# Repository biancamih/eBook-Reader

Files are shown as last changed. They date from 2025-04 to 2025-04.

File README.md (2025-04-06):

# OpenBook 
**Autor: Mihai Bianca-Ioana**

## Diagrama Bloc
```
                            +------------------------+
                            | USB-C Connector & ESD  |
                            +------------------------+
                                      |
                                      v
                             +------------------+
                             |   LDO Regulator   |
                             +------------------+
                                      |
                                      v
 +-------------------+       +------------------+       +---------------------+
 | Li-Po Charging IC | ----> | ESP32-C6 WROOM-1 | <-->  |    SD Card          |
 +-------------------+       +------------------+       +---------------------+
                                      |  ^   ^  ^
                                      |  |   |  |
         +------------------+         |  |   |  +---------------------+
         | Environmental     | -------+  |   +----------------+       |
         | Sensor (BME688)   |            |                    |       |
         +------------------+            |  +--------------+  |       |
                                         +->| NOR Flash     |<-+       |
                                         |  +--------------+          |
                                         |                             |
             +---------------+           +->| Battery Gauge |          |
             |   E-Paper     |<--------------+ (MAX17048)   |          |
             |   Driver      |           |  +---------------+          |
             +---------------+           |                             |
                                         +->| RTC (DS3231)  |<---------+
                                         |
                                         +->| Buttons       |
                                            +---------------+
```

## Bill Of  Materials (BOM)
| Component Name | Link | Datasheet Link |
|---|---|---|
| 112ATAARR03ATTEND | [Link](https://store.comet.srl.ro/Catalogue/Product/43497/) | [Link](https://www.attend.com.tw/data/download/file/112A-TAAR-R03.rar) |
| ADAFRUIT_CHIP-LED0603 | [Link](https://www.snapeda.com/parts/KP-1608SURCK/Kingbright/view-part/?ref=search&t=LED%200603) | [Link](https://www.snapeda.com/parts/KP-1608SURCK/Kingbright/datasheet/) |
| CAPCP3225X100N | [Link](https://www.snapeda.com/parts/CPH3225A/Seiko+Instruments/view-part/?ref=eda) | [Link](https://www.snapeda.com/parts/CPH3225A/Seiko%20Instruments/datasheet/) |
| DIOC1608X36N | [Link](https://www.snapeda.com/parts/PGB1010603MR/Littelfuse/view-part/?ref=eda) | [Link](https://www.snapeda.com/parts/PGB1010603MR/Littelfuse%20Inc./datasheet/) |
| EAGLE-LTSPICE_C0402 | [Link](https://componentsearchengine.com/part-view/CC0402MRX5R5BB106/YAGEO) | [Link](https://componentsearchengine.com/Datasheets/2/CC0402MRX5R5BB106.pdf) |
| ESP32_WROVER_AVX---SD0805S020S1R0_AVX_0  | [Link](https://ro.mouser.com/ProductDetail/KYOCERA-AVX/SD0805S020S1R0?qs=jCA%252BPfw4LHbpkAoSnwrdjw%3D%3D) | [Link](https://ro.mouser.com/datasheet/2/40/schottky-3165252.pdf) |
| ESP32_WROVER_BME680_PSON80P300X300X100-8N| [Link](https://www.snapeda.com/parts/BME680/Bosch/view-part/?welcome=home) | [Link](https://www.snapeda.com/parts/BME680/Bosch%20Sensortec/datasheet/) |
| ESP32_WROVER_EAGLE-LTSPICE_C0402 | [Link](https://componentsearchengine.com/part-view/CC0402MRX5R5BB106/YAGEO) | [Link](https://componentsearchengine.com/Datasheets/2/CC0402MRX5R5BB106.pdf) |
| ESP32_WROVER_EAGLE-LTSPICE_R0402 | [Link](https://componentsearchengine.com/part-view/R0402%201%25%20100%20K%20(RC0402FR-07100KL)/YAGEO) | [Link](https://www.yageo.com/upload/media/product/products/datasheet/rchip/PYu-RC_Group_51_RoHS_L_12.pdf)|
| ESP32_WROVER_SPARKFUN-DISCRETESEMI_SOT23-3| [Link](https://componentsearchengine.com/part-view/DMG2305UX-7/Diodes%20Incorporated) | [Link](https://www.diodes.com//assets/Datasheets/DMG2305UX.pdf) |
| ESP32_WROVER_SPARKFUN-IC-POWER_SOT23-5 | [Link](https://ro.mouser.com/ProductDetail/Microchip-Technology/MCP73831T-5ACI-OT?qs=hH%252BOa0VZEiAcgAcEkuamXg%3D%3D) | [Link](https://ro.mouser.com/datasheet/2/268/MCP73831_Family_Data_Sheet_DS20001984H-3441711.pdf) |
| ESP32C6_VARISTOR_CT/CN1812 | [Link](https://ro.mouser.com/ProductDetail/EPCOS-TDK/B72520T0350K062?qs=dEfas%2FXlABIszF52uu7vrg%3D%3D) | [Link](https://www.tdk-electronics.tdk.com/inf/75/db/CTVS_14/Surge_protection_series.pdf) |
| FH34SRJ24S05SH99 | [Link](https://ro.mouser.com/ProductDetail/Hirose-Connector/FH34SRJ-24S-0.5SH99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) | [Link](https://ro.mouser.com/datasheet/2/185/FH34SRJ_24S_0_5SH_99__CL0580_1255_6_99_2DDrawing_0-1615044.pdf)|
| IND_4828-WE-TPC_WRE | [Link](https://ro.mouser.com/ProductDetail/Wurth-Elektronik/744043680?qs=PGXP4M47uW6VkZq%252BkzjrHA%3D%3D)  | [Link](https://www.we-online.com/components/products/datasheet/744043680.pdf) |
| JST04_1MM_RA | [Link](https://ro.mouser.com/ProductDetail/Adafruit/4208?qs=PzGy0jfpSMtbScLbr0L5dw%3D%3D) | [Link](https://ro.mouser.com/ProductDetail/Adafruit/4208?qs=PzGy0jfpSMtbScLbr0L5dw%3D%3D) |
| MYBUTTON | [Link](https://industry.panasonic.com/global/en/products/control/switch/light-touch/number/evqpuj02k) | [Link](https://industry.panasonic.com/global/en/downloads?tab=catalog&small_g_cd=203&part_no=EVQPUJ02K)  |
| RCL_CT3528 | [Link](https://www.snapeda.com/parts/TAJB475K025RNJ/AVX/view-part/?t=capacitor%203528&con_ref=None) | [Link](https://www.snapeda.com/parts/TAJB475K025RNJ/AVX/datasheet/) |
| SAMACSYS_PARTS_USB4110GFA | [Link](https://componentsearchengine.com/part-view/USB4110-GF-A/GCT%20(GLOBAL%20CONNECTOR%20TECHNOLOGY)) | [Link](https://gct.co/files/drawings/usb4110.pdf) |
| SOD3716X135N | [Link](https://ro.mouser.com/ProductDetail/KYOCERA-AVX/SD0805S020S1R0?qs=jCA%252BPfw4LHbpkAoSnwrdjw%3D%3D) | [Link](https://ro.mouser.com/datasheet/2/40/schottky-3165252.pdf) |
| SOIC127P1032X265-16N | [Link](https://eu.mouser.com/ProductDetail/Wurth-Elektronik/744043680?qs=PGXP4M47uW6VkZq%252BkzjrHA%3D%3D)  | [Link](https://www.snapeda.com/parts/DS3231SN%23/Analog%20Devices/datasheet/) |
| SON127P600X800X80-9N | [Link](https://www.snapeda.com/parts/W25Q512JVEIQ/Winbond+Electronics/view-part/?ref=eda) | [Link](https://www.snapeda.com/parts/W25Q512JVEIQ/Winbond%20Electronics/datasheet/) |
| SON50P200X200X80-9N | [Link](https://www.snapeda.com/parts/MAX17048G+T10/Analog+Devices/view-part/?ref=eda) | [Link](https://www.snapeda.com/parts/MAX17048G+T10/Analog%20Devices/datasheet/) |
| SOT65P210X110-3N | [Link](https://componentsearchengine.com/part-view/SI1308EDL-T1-GE3/Vishay) | [Link](https://componentsearchengine.com/Datasheets/1/SI1308EDL-T1-GE3.pdf) |
| SOT95P280X125-5N | [Link](https://componentsearchengine.com/part-view/BD5229G-TR/ROHM%20Semiconductor) | [Link](https://datasheet.datasheetarchive.com/originals/distributors/Datasheets_SAMA/f2b9741ef86007909f138d561a359946.pdf) |
| SOT95P280X145-6N | [Link](https://www.snapeda.com/parts/USBLC6-2SC6Y/STMicroelectronics/view-part/?ref=eda) | [Link](https://www.snapeda.com/parts/USBLC6-2SC6Y/STMicroelectronics/datasheet/) |
| XCVR_ESP32-C6-WROOM-1-N8 | [Link](https://www.snapeda.com/parts/ESP32-C6-WROOM-1-N8/Espressif+Systems/view-part/?ref=eda) | [Link](https://www.snapeda.com/parts/ESP32-C6-WROOM-1-N8/Espressif%20Systems/datasheet/) |

## Descriere functionala hardware 

###  Arhitectura Hardware

Sistemul este bazat pe microcontrollerul **ESP32-C6-WROOM-1**, cu conectivitate Wi-Fi 6 și BLE, gândit pentru funcționare autonomă și consum redus de energie. Dispozitivul este alimentat de la o baterie Li-Po și poate fi programat prin USB-C. Componentele sunt interconectate prin SPI, I2C și GPIO.

---

### Alimentare și management baterie

- **USB-C Connector & ESD Protection**  
  Conector: `USB4110-GF-A`  
  Protecție ESD: `USBLC6-2SC6Y`

- **LDO Voltage Regulator**  
  Asigură 3.3V stabil pentru întreaga placă

- **Li-Po Battery Charger**  
  MCP73831 – circuit dedicat pentru încărcarea bateriei

- **Battery Gauge (MAX17048)**  
  Măsoară nivelul bateriei și comunică prin I2C

---

### Microcontroller principal

- **ESP32-C6-WROOM-1-N8**  
  RISC-V MCU cu Wi-Fi 6, BLE, 8MB flash intern  
  Rol: control central, comunicare cu senzori, logare, afișare

---

### Stocare

- **SD Card** – pentru loguri de date, firmware, fișiere
- **W25Q512 NOR Flash** – pentru memorie suplimentară SPI (64Mbit)

---

### Senzori & Ceas

- **BME688** – măsoară temperatură, umiditate, presiune și gaze (I2C)
- **DS3231** – ceas de timp real, cu precizie ridicată (I2C)

---

### Afișaj

- **E-Paper Driver + Conector**  
  Conectat prin SPI, controlat de ESP32  
  Alimentarea este comutabilă cu un MOSFET (SI1308EDL)

---

### Control și testare

- **Reset / Boot Buttons**
- **Qwiic/Stemma QT Connector** – extensii I2C
- **Test Pads** – debugging ușor

---

### Protecții

- **TVS Diodes**: `PGB1010603MR` – protecție ESD pe linii sensibile
- **Varistori**: protecție la supratensiuni

---

### Conexiuni interfețe

| Interfață | Dispozitive conectate |
|---|---|
| I2C | BME688, DS3231, MAX17048 |
| SPI | SD Card, NOR Flash, E-Paper Display |
| GPIO | Butoane, LED-uri, Power switches |

## Estimare Consum Energie

| Componentă | Mod activ (mA) | Standby (mA) | Deep sleep (µA) | Observații |
|---|---|---|---|---|
| **ESP32-C6** | 50–80 | ~2 | ~5 | Wi-Fi consumă cel mai mult |
| **BME688** | 2.1 | 0.15 | <1 | Măsurare la 1Hz |
| **DS3231 (RTC)** | 0.15 | 0.15 | 0.15 | Activ permanent |
| **MAX17048 (Battery Gauge)**| 0.06 | 0.006 | 0.006 | Foarte eficient |
| **E-paper Display** | 5–20 | 0 | 0 | Consumă doar în timpul refresh-ului |
| **SD Card (scriere activă)**| 30–100 | 0.2 | 0 | Alimentat doar la nevoie |
| **W25Q512 (SPI Flash)** | ~5 | 0.003 | <1 | Are mod standby foarte eficient |
| **LDO Regulator + pierderi**| 2–5 | 0.5 | 0.2 | Inclus în consum general |

---

##  Mapare pini ESP32-C6 

| Pin ESP32-C6 | Componentă | Funcție/Interfață | Motiv / Utilizare |
|---|---|---|---|
| **IO0** | Buton `BOOT` | GPIO / Input | Intrare folosită pentru intrarea în mod bootloader |
| **IO1** | `RTC DS3231` | I2C SDA | Comunicare cu ceasul de timp real |
| **IO2** | `RTC DS3231` | I2C SCL | Comunicare I2C |
| **IO3** | `BME688`, `MAX17048` | I2C SDA | Magistrală I2C partajată cu ceilalți senzori |
| **IO4** | `BME688`, `MAX17048` | I2C SCL | |
| **IO5** | `W25Q512 NOR Flash` | SPI CS | Chip select pentru memoria flash externă |
| **IO6** | `W25Q512`, `SD Card`, `E-Paper`| SPI CLK | Comun partajat între toate dispozitivele SPI |
| **IO7** | `W25Q512`, `SD Card`, `E-Paper`| SPI MISO | Date de la dispozitive SPI |
| **IO8** | `W25Q512`, `SD Card`, `E-Paper`| SPI MOSI | Date către dispozitivele SPI |
| **IO9** | `SD Card` | SPI CS | Selectare card SD |
| **IO10** | `E-Paper` | SPI CS | Selectare afișaj |
| **IO11** | `E-Paper` | BUSY / RESET / DC | Control afișaj e-paper |
| **IO12** | `E-Paper` | BUSY / RESET / DC | |
| **IO13** | `E-Paper` | BUSY / RESET / DC | |
| **IO18** | Buton `RESET` | GPIO / Input | Reset hardware |
| **IO19** | LED / Control MOSFET-uri | GPIO / Output | Power gating sau status LED-uri | |

## Observații și decizii de design:

- **SPI** este partajat între 3 periferice: SD card, NOR flash, e-paper. Fiecare are propriul pin CS.
- **I2C** este partajat între 3 dispozitive: BME688, DS3231 și MAX17048. Adresele sunt diferite.
- Pinul **IO0** este standard pentru BOOT, iar **IO18** este adesea folosit pentru RESET.
- GPIO suplimentare (ex. IO19, IO20) pot fi folosite pentru controlul alimentării modulelor (e.g., enable pin pe SD/e-paper).
- Se folosesc pinii **de jos (IO0–IO13)** pentru compatibilitate cu bootloader-ul și SPI flash extern.

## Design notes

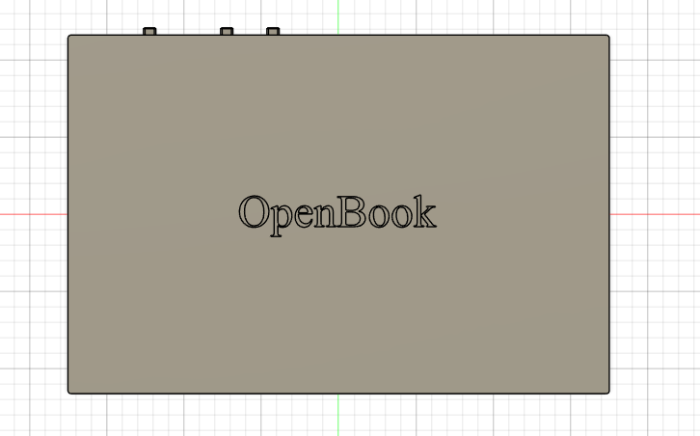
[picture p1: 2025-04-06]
Images/CaseView.png

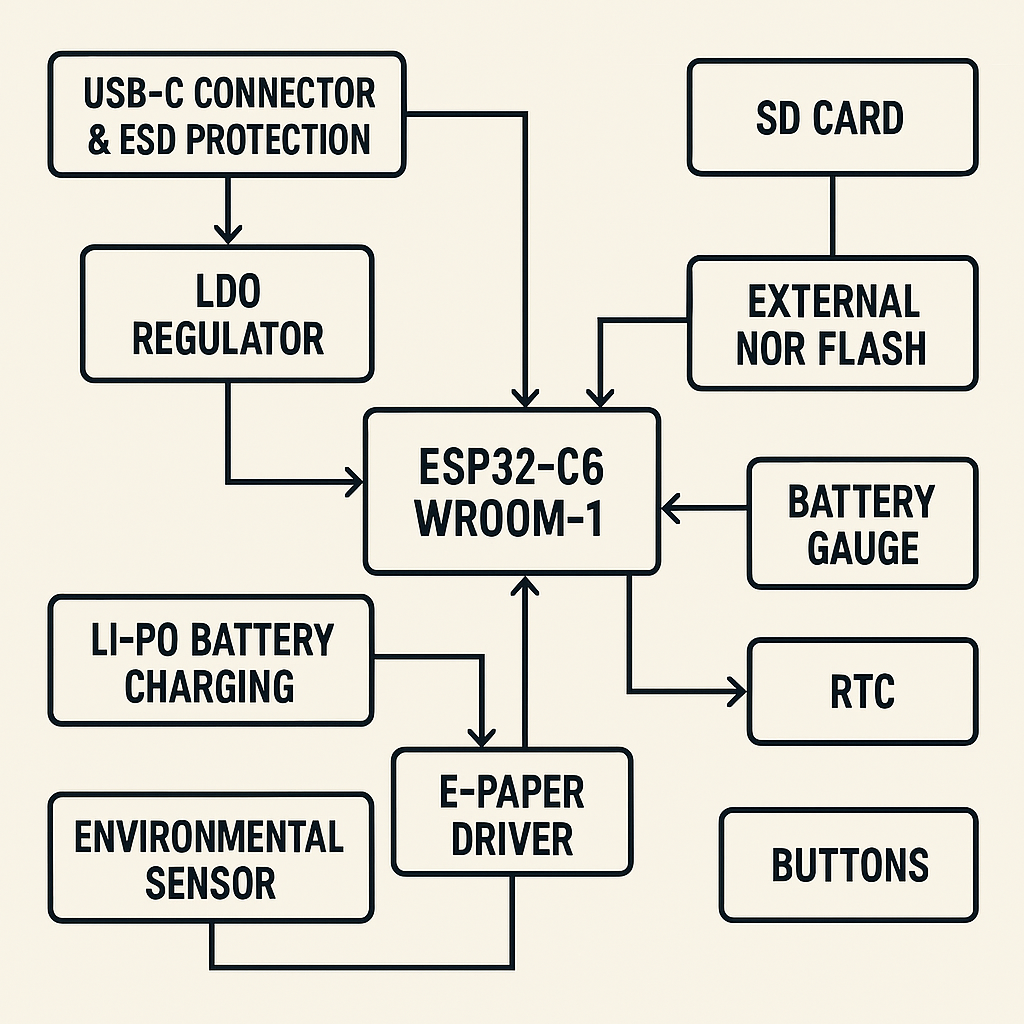
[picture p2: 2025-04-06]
Images/Schema.png

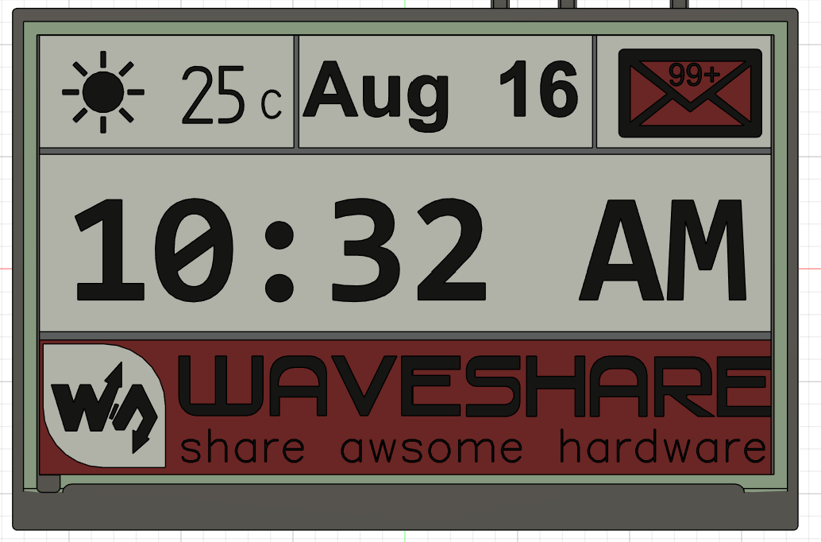
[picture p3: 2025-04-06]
Images/DisplayView.png

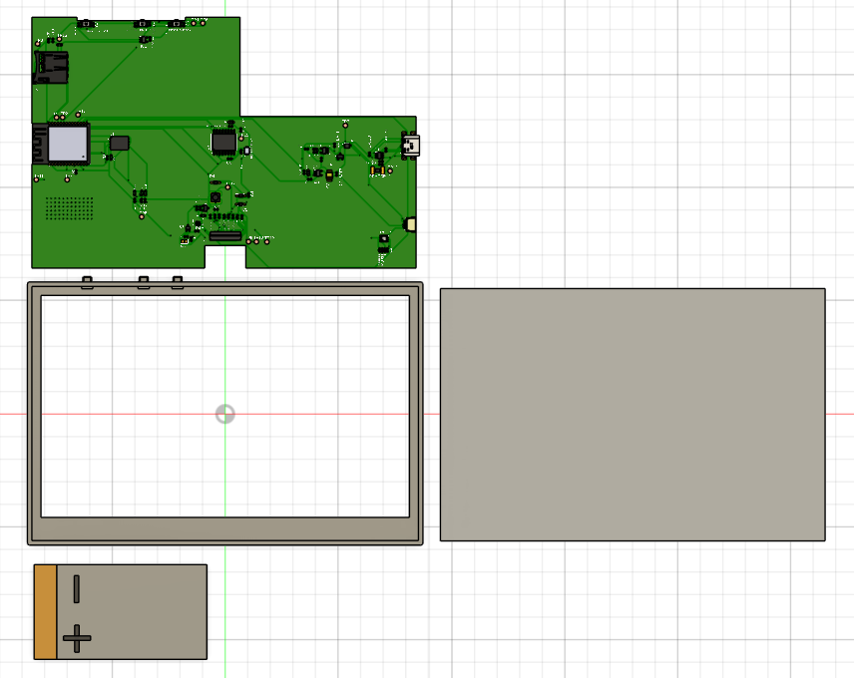
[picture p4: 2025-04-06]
Images/ExplodedView.png

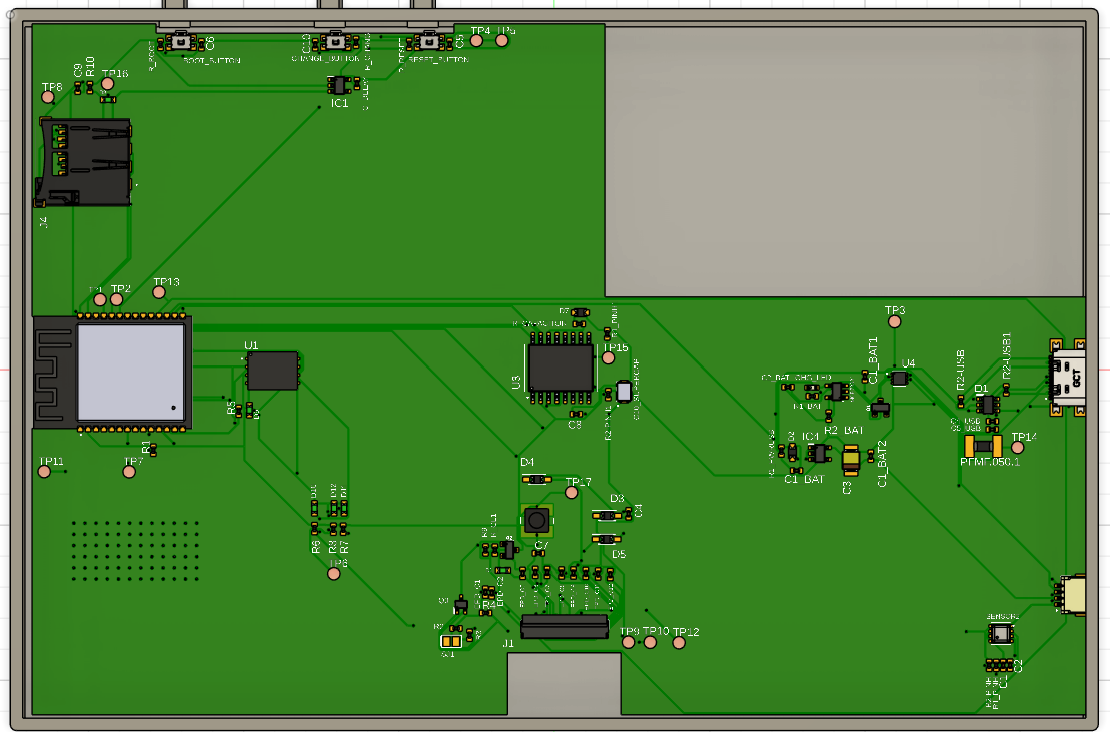
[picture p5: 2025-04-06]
Images/InsideWithoutBattery.png

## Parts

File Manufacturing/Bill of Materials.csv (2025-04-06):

Qty | Value | Device | Package | Parts | Description | ARROW_PART_NUMBER | ARROW_PRICE-STOCK | AVAILABILITY | CENTROID_NOT_SPECIFIED | CHECK_PRICES | COPYRIGHT | DATASHEET | DESCRIPTION | DETAILS | DIGIKEY_DESCRIPTION | DIGIKEY_PART_NUMBER | HEIGHT | LEAD_FREE | MANUFACTURER_NAME | MANUFACTURER_PART_NUMBER | MF | MFR_NAME | MOUSER_PART_NUMBER | MOUSER_PRICE-STOCK | MOUSER_TESTING_PART_NUMBER | MOUSER_TESTING_PRICE-STOCK | MP | MPN | NUME | PACKAGE | POPULARITY | PREFIX | PRICE | PROD_ID | PURCHASE-URL | ROHS | SNAPEDA_LINK | SPICEMODEL | SPICEPREFIX | TEMPERATURE_RANGE_HIGH | TEMPERATURE_RANGE_LOW | TP_SIGNAL_NAME | VALOARE | VALUE
1 |  | ADAFRUIT_LEDCHIP-LED0603 | ADAFRUIT_CHIP-LED0603 | CHG_LED | LED
1 |  | SJ | SJ | SJ1 | SMD solder JUMPER |  |  |  |  |  |  |  |  |  |  |  |  |  |  |  |  |  |  |  |  |  |  |  |  |  | 3
1 | 0.1uF/50V | ESP32_WROVER_EAGLE-LTSPICE_CC0402 | ESP32_WROVER_EAGLE-LTSPICE_C0402 | EPD_C5 | CAPACITOR, European symbol |  |  |  |  |  |  |  |  |  |  |  |  |  |  |  |  |  |  |  |  |  |  |  |  |  |  |  |  |  |  |  |  | NONE | C
1 | 0.47 | ESP32_WROVER_EAGLE-LTSPICE_RR0402 | ESP32_WROVER_EAGLE-LTSPICE_R0402 | R3 | RESISTOR, European symbol |  |  |  |  |  |  |  |  |  |  |  |  |  |  |  |  |  |  |  |  |  |  |  |  |  |  |  |  |  |  |  |  | NONE | R
1 | 100K | ESP32_WROVER_EAGLE-LTSPICE_RR0402 | ESP32_WROVER_EAGLE-LTSPICE_R0402 | R1_PWRUSB | RESISTOR, European symbol |  |  |  |  |  |  |  |  |  |  |  |  |  |  |  |  |  |  |  |  |  |  |  |  |  |  |  |  |  |  |  |  | NONE | R
8 | 100nF | ESP32_WROVER_EAGLE-LTSPICE_CC0402 | ESP32_WROVER_EAGLE-LTSPICE_C0402 | C1, C2, C4_USB, C6, C8, C9, C10, C_DELAY | CAPACITOR, European symbol |  |  |  |  |  |  |  |  |  |  |  |  |  |  |  |  |  |  |  |  |  |  |  |  |  |  |  |  |  |  |  |  | NONE | C
1 | 100uF TANT | RCL_CPOL-EUCT3528 | RCL_CT3528 | C3 | POLARIZED CAPACITOR, European symbol |  |  |  |  |  |  |  |  |  |  |  |  |  |  |  |  |  |  |  |  |  |  |  |  |  | 0 |  |  |  |  |  |  |  | C
16 | 10K | ESP32_WROVER_EAGLE-LTSPICE_RR0402 | ESP32_WROVER_EAGLE-LTSPICE_R0402 | R1, R1_PINH, R1_PINH1, R2-PINH, R2-PINH1, R4, R5, R6, R7, R8, R9, R10, R_BOOT, R_CHANGE, R_CL1, R_RESET | RESISTOR, European symbol |  |  |  |  |  |  |  |  |  |  |  |  |  |  |  |  |  |  |  |  |  |  |  |  |  |  |  |  |  |  |  |  | NONE | R
1 | 10uF | ESP32_WROVER_EAGLE-LTSPICE_CC0402 | ESP32_WROVER_EAGLE-LTSPICE_C0402 | C7 | CAPACITOR, European symbol |  |  |  |  |  |  |  |  |  |  |  |  |  |  |  |  |  |  |  |  |  |  |  |  |  |  |  |  |  |  |  |  | NONE | C
1 | 112A-TAAR-R03_ATTEND | 112A-TAAR-R03_ATTEND | 112ATAARR03ATTEND | J4 | Micro SD Card Socket, Push-Push Type, Top Mount, SMT, H=1.83mm, 10u |  |  |  |  |  |  |  | Micro SD Card Socket | Push-Push Type | Top Mount | SMT | H=1.83mm | 10u |  |  |  | 1.9mm |  | ATTEND | 112A-TAAR-R03 ATTEND
1 | 15 | ESP32_WROVER_EAGLE-LTSPICE_RR0402 | ESP32_WROVER_EAGLE-LTSPICE_R0402 | R_CAPACITOR | RESISTOR, European symbol |  |  |  |  |  |  |  |  |  |  |  |  |  |  |  |  |  |  |  |  |  |  |  |  |  |  |  |  |  |  |  |  | NONE | R
1 | 1uF | ESP32_WROVER_EAGLE-LTSPICE_CC0402 | ESP32_WROVER_EAGLE-LTSPICE_C0402 | C5 | CAPACITOR, European symbol |  |  |  |  |  |  |  |  |  |  |  |  |  |  |  |  |  |  |  |  |  |  |  |  |  |  |  |  |  |  |  |  | NONE | C
9 | 1uF/50V | ESP32_WROVER_EAGLE-LTSPICE_CC0402 | ESP32_WROVER_EAGLE-LTSPICE_C0402 | EPD_C1, EPD_C2, EPD_C6, EPD_C7, EPD_C8, EPD_C9, EPD_C10, EPD_C11, EPD_C12 | CAPACITOR, European symbol |  |  |  |  |  |  |  |  |  |  |  |  |  |  |  |  |  |  |  |  |  |  |  |  |  |  |  |  |  |  |  |  | NONE | C
1 | 2.2 | ESP32_WROVER_EAGLE-LTSPICE_RR0402 | ESP32_WROVER_EAGLE-LTSPICE_R0402 | R2 | RESISTOR, European symbol |  |  |  |  |  |  |  |  |  |  |  |  |  |  |  |  |  |  |  |  |  |  |  |  |  |  |  |  |  |  |  |  | NONE | R
1 | 200 | ESP32_WROVER_EAGLE-LTSPICE_RR0402 | ESP32_WROVER_EAGLE-LTSPICE_R0402 | R1_BAT | RESISTOR, European symbol |  |  |  |  |  |  |  |  |  |  |  |  |  |  |  |  |  |  |  |  |  |  |  |  |  |  |  |  |  |  |  |  | NONE | R
2 | 20V/4.2A/52mO/1.4W | ESP32_WROVER_SPARKFUN-DISCRETESEMI_MOSFET_PCH-DMG2305UX-7 | ESP32_WROVER_SPARKFUN-DISCRETESEMI_SOT23-3 | Q1, Q2 | P-channel MOSFETs |  |  |  |  |  |  |  |  | DMG2305UX-7 |  |  |  |  |  |  |  |  |  |  |  |  |  |  |  |  |  |  |  | TRAN-14388 |  |  |  |  |  |  |  |  |  | 20V/4.2A/52mO/1.4W
1 | 2K | ESP32_WROVER_EAGLE-LTSPICE_RR0402 | ESP32_WROVER_EAGLE-LTSPICE_R0402 | R2_BAT | RESISTOR, European symbol |  |  |  |  |  |  |  |  |  |  |  |  |  |  |  |  |  |  |  |  |  |  |  |  |  |  |  |  |  |  |  |  | NONE | R
2 | 4.7uF | EAGLE-LTSPICE_CC0402 | EAGLE-LTSPICE_C0402 | C1_BAT1, C1_BAT2 | CAPACITOR, European symbol |  |  |  |  |  |  |  |  |  |  |  |  |  |  |  |  |  |  |  |  |  |  |  |  |  |  |  |  |  |  |  |  | NONE | C
3 | 4.7uF | ESP32_WROVER_EAGLE-LTSPICE_CC0402 | ESP32_WROVER_EAGLE-LTSPICE_C0402 | C1_BAT, C2_BAT, C5_USB | CAPACITOR, European symbol |  |  |  |  |  |  |  |  |  |  |  |  |  |  |  |  |  |  |  |  |  |  |  |  |  |  |  |  |  |  |  |  | NONE | C
1 | 4.7uF/25V | ESP32_WROVER_EAGLE-LTSPICE_CC0402 | ESP32_WROVER_EAGLE-LTSPICE_C0402 | C4 | CAPACITOR, European symbol |  |  |  |  |  |  |  |  |  |  |  |  |  |  |  |  |  |  |  |  |  |  |  |  |  |  |  |  |  |  |  |  | NONE | C
2 | 5k1 | ESP32_WROVER_EAGLE-LTSPICE_RR0402 | ESP32_WROVER_EAGLE-LTSPICE_R0402 | R2-USB, R2-USB1 | RESISTOR, European symbol |  |  |  |  |  |  |  |  |  |  |  |  |  |  |  |  |  |  |  |  |  |  |  |  |  |  |  |  |  |  |  |  | NONE | R
1 | 68uH | 744043680IND_4828-WE-TPC_WRE | IND_4828-WE-TPC_WRE | L1 |  |  |  |  |  |  | Copyright (C) 2024 Ultra Librarian. All rights reserved. |  |  |  |  |  |  |  |  | 744043680 |  | Wurth Electronics |  |  |  |  |  |  |  |  |  |  |  |  |  |  |  |  |  |  |  |  | 68uH
1 | BD5229G-TR | BD5229G-TR | SOT95P280X125-5N | IC1 | Voltage Detector with Adjustable Delay Time: CMOS processes are utilized to develop high precision, low current consumption CMOS reset ICs that allow arbitrary setting of the delay time. The extensive lineup includes both Nch Open Drain and CMOS output types in a wide range of detection voltages (from 2.3V to 6.0V, in 0.1V steps), enabling selection of the ideal solution based on customer requirements. In addition, the entire series is of course both lead-free and RoHS-compliant. |  |  |  |  |  |  |  | Voltage Detector with Adjustable Delay Time: CMOS processes are utilized to develop high precision | low current consumption CMOS reset ICs that allow arbitrary setting of the delay time. The extensive lineup includes both Nch Open Drain and CMOS output types in a wide range of detection voltages (from 2.3V to 6.0V | in 0.1V steps) | enabling selection of the ideal solution based on customer requirements. In addition | the entire series is of course both lead-free and RoHS-compliant. |  |  |  | 1.25mm |  | ROHM Semiconductor | BD5229G-TR |  |  | 755-BD5229G-TR | https://www.mouser.co.uk/ProductDetail/ROHM-Semiconductor/BD5229G-TR?qs=4kLU8WoGk0vvnhrrYwdszw%3D%3D
1 | BME688 | ESP32_WROVER_BME680_BME680 | ESP32_WROVER_BME680_PSON80P300X300X100-8N | SENSOR2 | Integrated Environmental Unit |  |  | Unavailable |  |  |  |  | Integrated Environmental Unit |  |  |  |  |  |  |  | Bosch Sensortec |  |  |  |  |  | BME680 |  |  | LGA-8 Bosch Tools |  |  | None
3 | BUTTON_CUSYOMV1 | BUTTON_CUSYOMV1 | MYBUTTON | BOOT_BUTTON, CHANGE_BUTTON, RESET_BUTTON
1 | CPH3225A | CPH3225A | CAPCP3225X100N | C10_SUPERCAP | Cap 0.011F 3.3V 1210 Flat Check availability |  |  | Not in stock |  | https://www.snapeda.com/parts/CPH3225A/Seiko+Instruments/view-part/?ref=eda |  |  | 11 mF (EDLC) Supercapacitor 3.3 V 1210 (3225 Metric) - - |  |  |  |  |  |  |  | Seiko Instruments |  |  |  |  |  | CPH3225A |  |  | 1210 Seiko |  |  | None |  | https://www.snapeda.com/api/url_track_click_mouser/?unipart_id=562593&manufacturer=Seiko Instruments&part_name=CPH3225A&search_term=None |  | https://www.snapeda.com/parts/CPH3225A/Seiko+Instruments/view-part/?ref=snap
1 | DS3231SN# | DS3231SN# | SOIC127P1032X265-16N | U3 | Real Time Clock Serial 16-Pin SOIC W T/R Check availability |  |  | In Stock |  | https://www.snapeda.com/parts/DS3231SN%23/Analog+Devices/view-part/?ref=eda |  |  | Extremely Accurate I²C-Integrated RTC/TCXO/Crystal |  |  |  |  |  |  |  | Analog Devices |  |  |  |  |  | DS3231SN# |  |  | SOIC-16 Maxim |  |  | None |  | https://www.snapeda.com/api/url_track_click_mouser/?unipart_id=99048&manufacturer=Analog Devices&part_name=DS3231SN#&search_term=None |  | https://www.snapeda.com/parts/DS3231SN%23/Analog+Devices/view-part/?ref=snap
1 | ESP32-C6-WROOM-1-N8 | ESP32-C6-WROOM-1-N8 | XCVR_ESP32-C6-WROOM-1-N8 | U2 | Check availability |  |  | In Stock |  | https://www.snapeda.com/parts/ESP32-C6-WROOM-1-N8/Espressif+Systems/view-part/?ref=eda |  |  | Multiprotocol Modules ESP32-C6 module | Wi-Fi 6 in 2.4 GHz band | Bluetooth 5 | Zigbee 3.0 and Thread. ESP34-WROOM Compatible - ENGINEERING SAMPLE |  |  |  |  |  |  |  | Espressif Systems |  |  |  |  |  | ESP32-C6-WROOM-1-N8 |  |  | None |  |  | None |  |  |  | https://www.snapeda.com/parts/ESP32-C6-WROOM-1-N8/Espressif+Systems/view-part/?ref=snap
1 | ESP32C6_VARISTORCN1812 | ESP32C6_VARISTORCN1812 | ESP32C6_VARISTOR_CT/CN1812 | PFMF.050.1 | VARISTOR |  |  |  |  |  |  |  |  |  |  |  |  |  |  |  |  |  |  |  |  |  |  |  |  |  | 0
1 | ESP32_WROVER_AVX---SD0805S020S1R0_AVX_SD0805S020S1R0_0_0AVX_SD0805S020S1R0_0_0 | ESP32_WROVER_AVX---SD0805S020S1R0_AVX_SD0805S020S1R0_0_0AVX_SD0805S020S1R0_0_0 | ESP32_WROVER_AVX---SD0805S020S1R0_AVX_SD0805S020S1R0_0 | D2 | Schottky Barrier Rectifier Diode |  |  |  | No |  |  | http://datasheets.avx.com/schottky.pdf |  | SD0805S020S1R0 | DIODE SCHOTTKY 20V 1A 0805 | 478-7800-1-ND |  | yes |  |  | AVX |  | 581-SD0805S020S1R0 |  |  |  |  |  |  | 0805 (2012 metric) |  | D |  |  |  | yes |  |  |  | +125°C | -55°C
1 | ESP32_WROVER_AVX---SD0805S020S1R0_AVX_SD0805S020S1R0_0_0AVX_SD0805S020S1R0_0_0 | ESP32_WROVER_AVX---SD0805S020S1R0_AVX_SD0805S020S1R0_0_0AVX_SD0805S020S1R0_0_0 | ESP32_WROVER_AVX---SD0805S020S1R0_AVX_SD0805S020S1R0_0 | D7 | Schottky Barrier Rectifier Diode |  |  |  | No |  |  | http://datasheets.avx.com/schottky.pdf |  |  | DIODE SCHOTTKY 20V 1A 0805 | 478-7800-1-ND |  | yes |  |  | AVX |  | 581-SD0805S020S1R0 |  |  |  |  |  |  | 0805 (2012 metric) |  | D |  |  |  | yes |  |  |  | +125°C | -55°C |  | SD0805S020S1R0
1 | ESP32_WROVER_SPARKFUN-IC-POWER_MCP73831 | ESP32_WROVER_SPARKFUN-IC-POWER_MCP73831 | ESP32_WROVER_SPARKFUN-IC-POWER_SOT23-5 | MCP73831 | MCP73831T Li-Ion, Li-Pol Controller |  |  |  |  |  |  |  |  |  |  |  |  |  |  |  |  |  |  |  |  |  |  |  |  |  |  |  |  | IC-09995
1 | FH34SRJ-24S-0.5SH_99_ | FH34SRJ-24S-0.5SH_99_ | FH34SRJ24S05SH99 | J1 | (0.50mm) Surface Mount, Right Angle |  |  |  |  |  |  |  | 24 Position FFC | FPC Connector Contacts | (0.50mm) Surface Mount | Right Angle |  |  |  | 1.1mm |  | Hirose | FH34SRJ-24S-0.5SH(99) |  |  | 798-FH34SRJ24S05SH99 | https://www.mouser.co.uk/ProductDetail/Hirose-Connector/FH34SRJ-24S-0.5SH99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
1 | MAX17048G+T10 | MAX17048G+T10 | SON50P200X200X80-9N | U4 | Check availability |  |  | In Stock |  | https://www.snapeda.com/parts/MAX17048G+T10/Analog+Devices/view-part/?ref=eda |  |  | 3µA 1-Cell/2-Cell Fuel Gauge with ModelGauge |  |  |  |  |  |  |  | Analog Devices |  |  |  |  |  | MAX17048G+T10 |  |  | TDFN-8 Maxim |  |  | None |  | https://www.snapeda.com/api/url_track_click_mouser/?unipart_id=329239&manufacturer=Analog Devices&part_name=MAX17048G+T10&search_term=None |  | https://www.snapeda.com/parts/MAX17048G+T10/Analog+Devices/view-part/?ref=snap
3 | MBR0530 | MBR0530 | SOD3716X135N | D3, D4, D5 | ON SEMICONDUCTOR - MBR0530 - DIODE, SCHOTTKY, 0.5A, 30V, SOD-123 |  |  | In Stock |  | https://www.snapeda.com/parts/MBR0530/Onsemi/view-part/?ref=eda |  |  | Diode Schottky 30 V 500mA Surface Mount SOD-123 |  |  |  |  |  |  |  | ON Semiconductor |  |  |  |  |  | MBR0530 |  |  | SOD-123-2 ON Semiconductor |  |  | None |  | https://www.snapeda.com/api/url_track_click_mouser/?unipart_id=179458&manufacturer=ON Semiconductor&part_name=MBR0530&search_term=None |  | https://www.snapeda.com/parts/MBR0530/Onsemi/view-part/?ref=snap
6 | PGB1010603MR | PGB1010603MR | DIOC1608X36N | D6, D8, D9, D10, D11, D12 | Check availability |  |  | In Stock |  | https://www.snapeda.com/parts/PGB1010603MR/Littelfuse/view-part/?ref=eda |  |  | 150V (Typ) Clamp - Ipp Tvs Diode Surface Mount 0603 (1608 Metric) |  |  |  |  |  |  |  | Littelfuse Inc. |  |  |  |  |  | PGB1010603MR |  |  | 0603 Littelfuse Inc. |  |  | None |  | https://www.snapeda.com/api/url_track_click_mouser/?unipart_id=5659453&manufacturer=Littelfuse Inc.&part_name=PGB1010603MR&search_term=None |  | https://www.snapeda.com/parts/PGB1010603MR/Littelfuse/view-part/?ref=snap
1 | QWIIC_RIGHT_ANGLE | QWIIC_CONNECTORJS-1MM | JST04_1MM_RA | J3 | SparkFun I2C Standard Qwiic Connector |  |  |  |  |  |  |  |  |  |  |  |  |  |  |  |  |  |  |  |  |  |  |  |  |  |  |  |  | CONN-13694 |  |  |  |  |  |  |  |  |  | QWIIC_RIGHT_ANGLE
1 | SAMACSYS_PARTS_USB4110-GF-A | SAMACSYS_PARTS_USB4110-GF-A | SAMACSYS_PARTS_USB4110GFA | J2 | CONN USB 2.0 TYPE-C R/A SMT |  |  |  |  |  |  |  | CONN USB 2.0 TYPE-C R/A SMT |  |  |  | 3.26mm |  | GCT (GLOBAL CONNECTOR TECHNOLOGY) | USB4110-GF-A |  |  | 640-USB4110-GF-A | https://www.mouser.co.uk/ProductDetail/GCT/USB4110-GF-A?qs=KUoIvG%2F9IlYiZvIXQjyJeA%3D%3D
1 | SI1308EDL-T1-GE3 | SI1308EDL-T1-GE3 | SOT65P210X110-3N | Q3 | MOSFET N-Ch 30V 1.5A TrenchFET SC70 Vishay Si1308EDL-T1-GE3 N-channel MOSFET Transistor, 1.5 A, 30 V, 3-Pin SC-70 |  |  | In Stock |  | https://www.snapeda.com/parts/SI1308EDL-T1-GE3/Vishay+Siliconix/view-part/?ref=eda |  |  | Si1308EDL-T1-GE3 N-channel MOSFET Transistor | 1.5 A | 30 V | 3-Pin SC-70 | Siliconix / Vishay SI1308EDL-T1-GE3 |  |  |  |  |  |  |  | Vishay Siliconix |  |  |  |  |  | SI1308EDL-T1-GE3 |  |  | SOT-323 Vishay Semiconductor |  |  | None |  | https://www.snapeda.com/api/url_track_click_mouser/?unipart_id=274603&manufacturer=Vishay Siliconix&part_name=SI1308EDL-T1-GE3&search_term=None |  | https://www.snapeda.com/parts/SI1308EDL-T1-GE3/Vishay+Siliconix/view-part/?ref=snap
17 | TPTP20R | TPTP20R | TP20R | TP1, TP2, TP3, TP4, TP5, TP6, TP7, TP8, TP9, TP10, TP11, TP12, TP13, TP14, TP15, TP16, TP17 | Test pad |  |  |  |  |  |  |  |  |  |  |  |  |  |  |  |  |  |  |  |  |  |  |  |  |  | 2
1 | USBLC6-2SC6Y | USBLC6-2SC6Y | SOT95P280X145-6N | D1 | Low Cap. ESD Protection Auto SOT-23-6 STMicroelectronics USBLC6-2SC6Y, Dual Uni-Directional TVS Diode Array, 6-Pin SOT-23 |  |  | In Stock |  | https://www.snapeda.com/parts/USBLC6-2SC6Y/STMicroelectronics/view-part/?ref=eda |  |  | 17V Clamp 5A (8/20µs) Ipp Tvs Diode Surface Mount SOT-23-6 | USBLC6-2SC6Y |  |  |  |  |  |  | STMicroelectronics |  |  |  |  |  | USBLC6-2SC6Y |  | D1 | SOT-23-6 STMicroelectronics |  |  | None |  |  |  | https://www.snapeda.com/parts/USBLC6-2SC6Y/STMicroelectronics/view-part/?ref=snap
1 | W25Q512JVEIQ | W25Q512JVEIQ | SON127P600X800X80-9N | U1 | Check availability |  |  | In Stock |  | https://www.snapeda.com/parts/W25Q512JVEIQ/Winbond+Electronics/view-part/?ref=eda |  |  | FLASH - NOR Memory IC 512Mb (64M x 8) SPI - Quad I/O 133 MHz 8-WSON (8x6) |  |  |  |  |  |  |  | Winbond Electronics |  |  |  |  |  | W25Q512JVEIQ |  |  | Package |  |  | None |  |  |  | https://www.snapeda.com/parts/W25Q512JVEIQ/Winbond+Electronics/view-part/?ref=snap
1 | XC6220A331MR-G | XC6220A331MR-G | SOT95P280X120-5N | IC4 | LDO Voltage Regulators |  |  |  |  |  |  |  | LDO Voltage Regulators |  |  |  | 1.2mm |  | Torex | XC6220A331MR-G |  |  | 865-XC6220A331MR-G | https://www.mouser.co.uk/ProductDetail/Torex-Semiconductor/XC6220A331MR-G?qs=AsjdqWjXhJ8ZSWznL1J0gg%3D%3D

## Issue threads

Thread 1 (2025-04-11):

Grosime placuta PCB

tiberiugila, 2025-04-11:
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

Grosimea placutei ar trebui sa fie de 1mm, nu de 1,6mm. Probabil este o problema de import de la fusion

Closed 2025-04-13.

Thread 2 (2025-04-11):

Text in plus la Schematic

tiberiugila, 2025-04-11:
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

Anumite texte nu ar trebui sa fie in schematic, mai exact cel de 68uH (prima poza) si SAMACSYS PARTS USB4110-07 cu ESP32C6_VARISTORCN1812(in a doua poza)

Ti-am atasat si schema electrica mai jos pentru a putea accesa mai usor documentul
https://ocw.cs.pub.ro/courses/_media/tsc/deskassistant_v15.pdf

Closed 2025-04-13.

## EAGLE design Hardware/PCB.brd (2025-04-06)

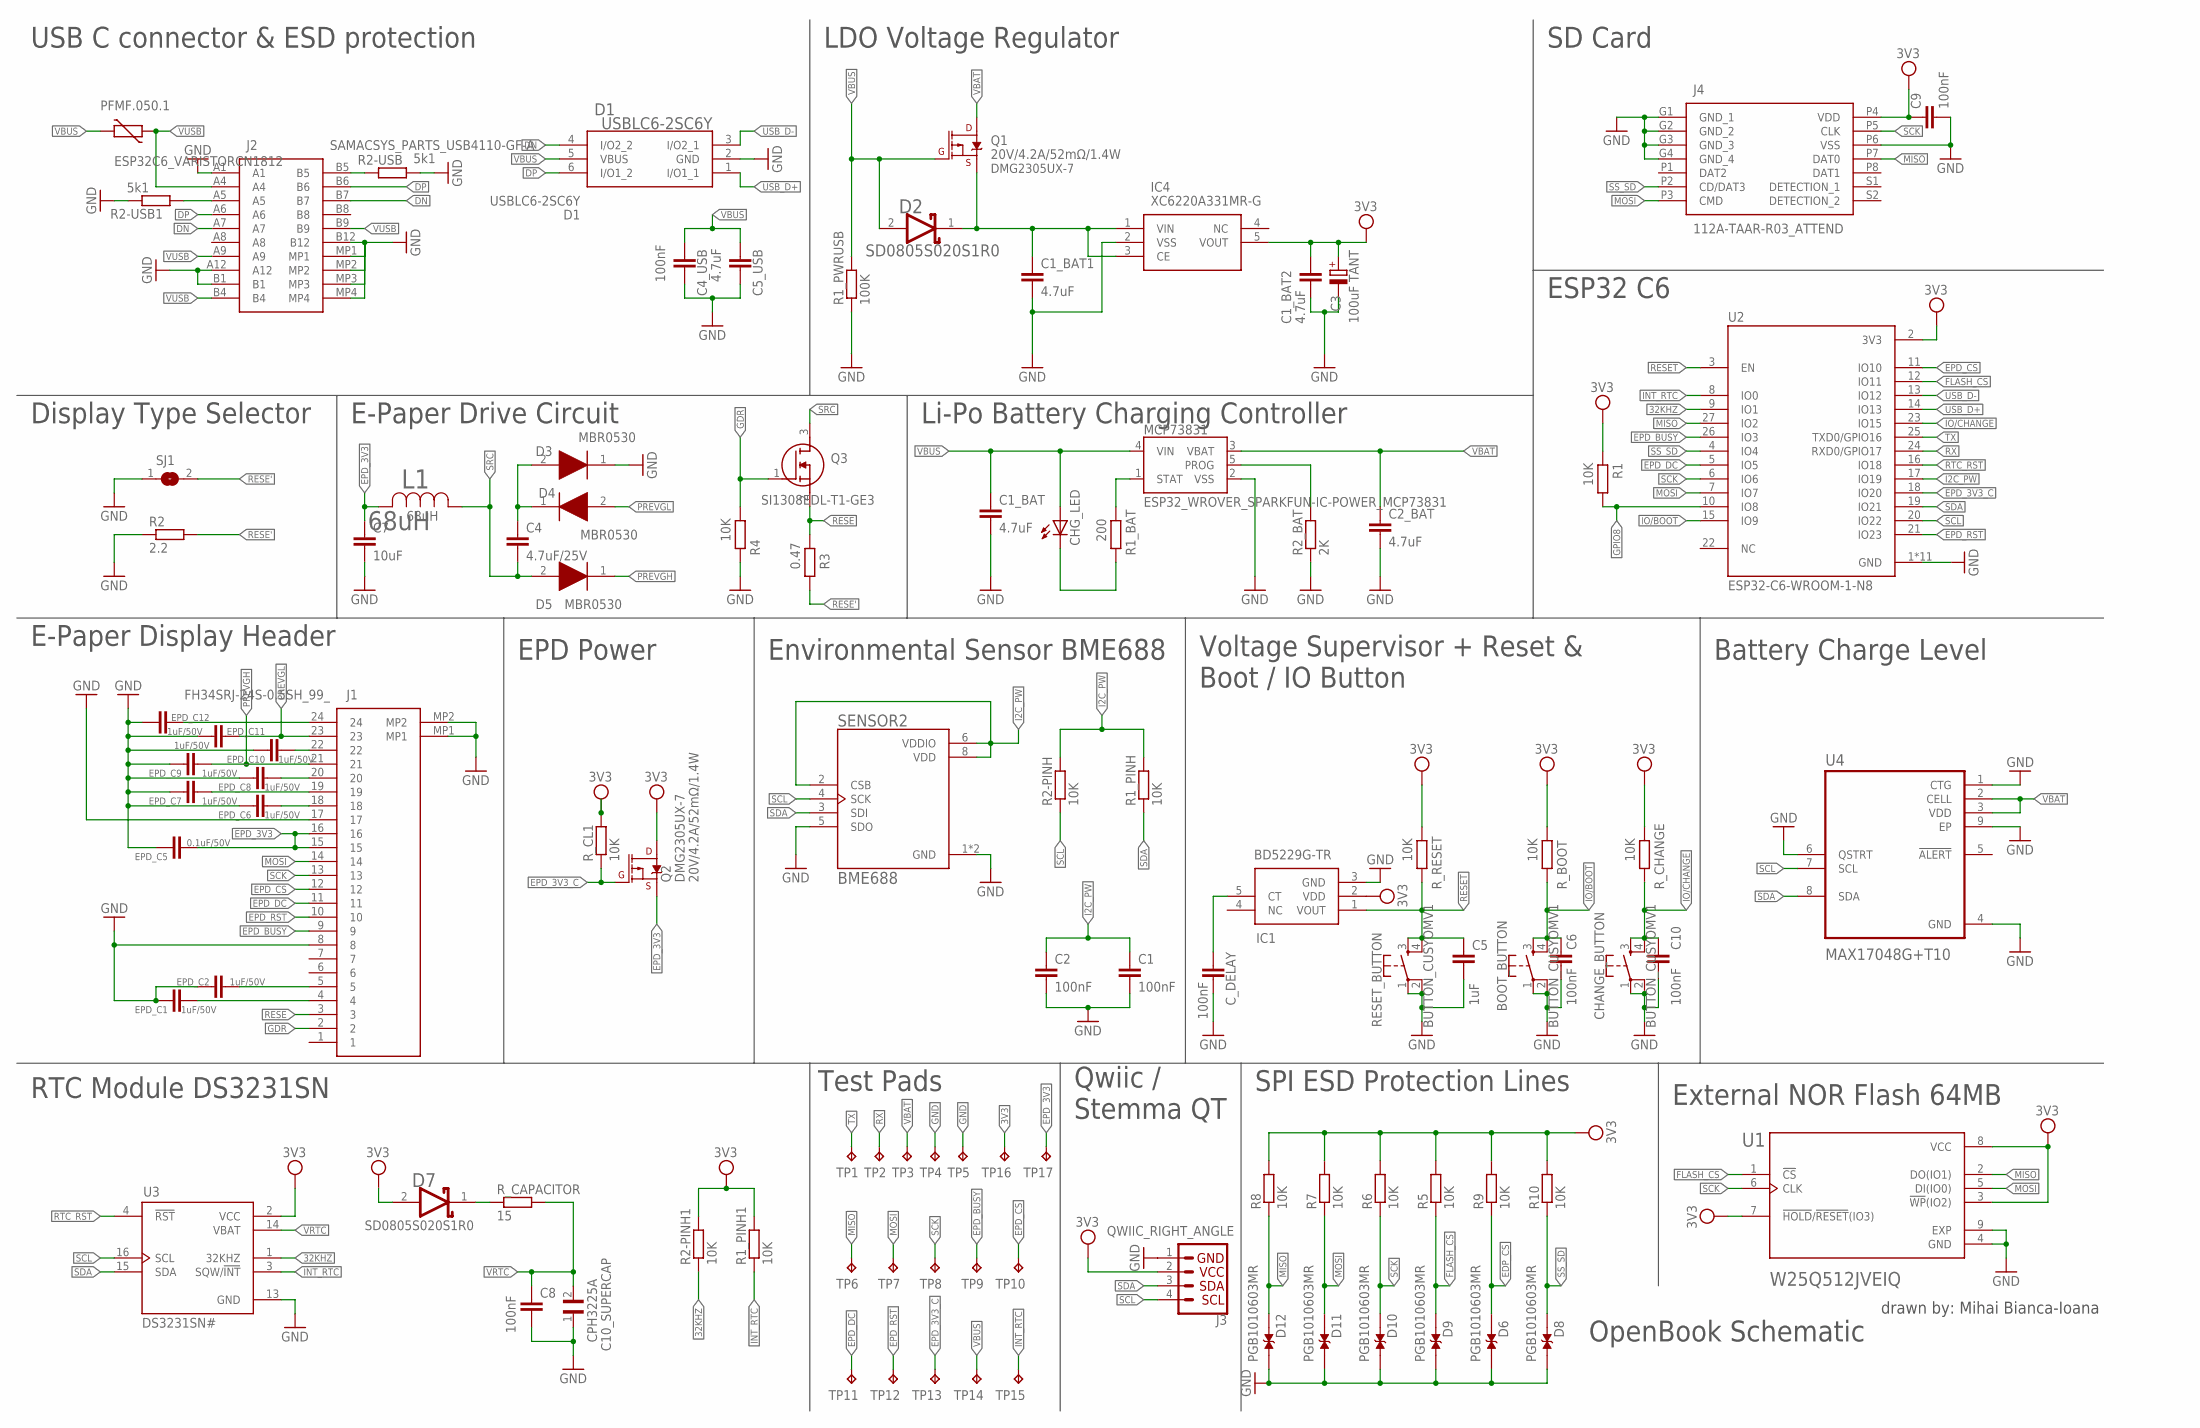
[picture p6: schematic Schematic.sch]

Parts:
BOOT_BUTTON: BUTTON_CUSYOMV1; MYBUTTON
C1, C2, C4_USB, C6, C8, C9, C10: 100nF; ESP32_WROVER_EAGLE-LTSPICE_C0402
C1_BAT, C2_BAT, C5_USB: 4.7uF; ESP32_WROVER_EAGLE-LTSPICE_C0402
C1_BAT1, C1_BAT2: 4.7uF; EAGLE-LTSPICE_C0402
C3: 100uF TANT; RCL_CT3528
C4: 4.7uF/25V; ESP32_WROVER_EAGLE-LTSPICE_C0402
C5: 1uF; ESP32_WROVER_EAGLE-LTSPICE_C0402
C7: 10uF; ESP32_WROVER_EAGLE-LTSPICE_C0402
C10_SUPERCAP: CPH3225A; CAPCP3225X100N
CHANGE_BUTTON: BUTTON_CUSYOMV1; MYBUTTON
CHG_LED: ADAFRUIT_LEDCHIP-LED0603; ADAFRUIT_CHIP-LED0603
C_DELAY: 100nF; ESP32_WROVER_EAGLE-LTSPICE_C0402
D1: USBLC6-2SC6Y; SOT95P280X145-6N
D2, D7: ESP32_WROVER_AVX---SD0805S020S1R0_AVX_SD0805S020S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; ESP32_WROVER_AVX---SD0805S020S1R0_AVX_SD0805S020S1R0_0
D3, D4, D5: MBR0530; SOD3716X135N
D6, D8, D9, D10, D11, D12: PGB1010603MR; DIOC1608X36N
EPD_C1, EPD_C2, EPD_C6, EPD_C7, EPD_C8, EPD_C9, EPD_C10, EPD_C11, EPD_C12: 1uF/50V; ESP32_WROVER_EAGLE-LTSPICE_C0402
EPD_C5: 0.1uF/50V; ESP32_WROVER_EAGLE-LTSPICE_C0402
IC1: BD5229G-TR; SOT95P280X125-5N
IC4: XC6220A331MR-G; SOT95P280X120-5N
J1: FH34SRJ-24S-0.5SH_99_; FH34SRJ24S05SH99
J2: SAMACSYS_PARTS_USB4110-GF-A; SAMACSYS_PARTS_USB4110GFA
J3: QWIIC_RIGHT_ANGLE; JST04_1MM_RA
J4: 112A-TAAR-R03_ATTEND; 112ATAARR03ATTEND
L1: 68uH; IND_4828-WE-TPC_WRE
MCP73831: ESP32_WROVER_SPARKFUN-IC-POWER_MCP73831; ESP32_WROVER_SPARKFUN-IC-POWER_SOT23-5
PFMF.050.1: ESP32C6_VARISTORCN1812; ESP32C6_VARISTOR_CT/CN1812
Q1, Q2: 20V/4.2A/52mΩ/1.4W; ESP32_WROVER_SPARKFUN-DISCRETESEMI_SOT23-3
Q3: SI1308EDL-T1-GE3; SOT65P210X110-3N
R1, R1_PINH, R1_PINH1, R2-PINH, R2-PINH1, R4, R5, R6, R7, R8, R9, R10: 10K; ESP32_WROVER_EAGLE-LTSPICE_R0402
R1_BAT: 200; ESP32_WROVER_EAGLE-LTSPICE_R0402
R1_PWRUSB: 100K; ESP32_WROVER_EAGLE-LTSPICE_R0402
R2: 2.2; ESP32_WROVER_EAGLE-LTSPICE_R0402
R2-USB, R2-USB1: 5k1; ESP32_WROVER_EAGLE-LTSPICE_R0402
R2_BAT: 2K; ESP32_WROVER_EAGLE-LTSPICE_R0402
R3: 0.47; ESP32_WROVER_EAGLE-LTSPICE_R0402
RESET_BUTTON: BUTTON_CUSYOMV1; MYBUTTON
R_BOOT: 10K; ESP32_WROVER_EAGLE-LTSPICE_R0402
R_CAPACITOR: 15; ESP32_WROVER_EAGLE-LTSPICE_R0402
R_CHANGE: 10K; ESP32_WROVER_EAGLE-LTSPICE_R0402
R_CL1: 10K; ESP32_WROVER_EAGLE-LTSPICE_R0402
R_RESET: 10K; ESP32_WROVER_EAGLE-LTSPICE_R0402
SENSOR2: BME688; ESP32_WROVER_BME680_PSON80P300X300X100-8N
SJ1: SJ
TP1, TP2, TP3, TP4, TP5, TP6, TP7, TP8, TP9, TP10, TP11, TP12, TP13, TP14, TP15, TP16, TP17: TPTP20R; TP20R
U1: W25Q512JVEIQ; SON127P600X800X80-9N
U2: ESP32-C6-WROOM-1-N8; XCVR_ESP32-C6-WROOM-1-N8
U3: DS3231SN#; SOIC127P1032X265-16N
U4: MAX17048G+T10; SON50P200X200X80-9N

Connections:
3V3: C1_BAT2.1, C3.+, C9.1, D7.2 (ANODE), IC1.2 (VDD), IC4.5 (VOUT), J3.2, J4.P4 (VDD), Q2.3 (D), R1.2, R1_PINH1.2, R2-PINH1.2, R5.2, R6.2, R7.2, R8.2, R9.2, R10.2, R_BOOT.2, R_CHANGE.2, R_CL1.2, R_RESET.2, TP16.TP, U1.3 (!WP!(IO2)), U1.7 (!HOLD!/!RESET!(IO3)), U1.8 (VCC), U2.2 (3V3), U3.2 (VCC)
32KHZ: R2-PINH1.1, U2.9 (IO1), U3.1 (32KHZ)
DN: D1.4 (I/O2_2), J2.A7, J2.B7
DP: D1.6 (I/O1_2), J2.A6, J2.B6
EDP_CS: D6.1, R9.1
EPD_3V3: C7.1, EPD_C5.2, J1.15, J1.16, L1.2, Q2.2 (S), TP17.TP
EPD_3V3_C: Q2.1 (G), R_CL1.1, TP13.TP, U2.18 (IO20)
EPD_BUSY: J1.9, TP9.TP, U2.26 (IO3)
EPD_CS: J1.12, TP10.TP, U2.11 (IO10)
EPD_DC: J1.11, TP11.TP, U2.5 (IO5)
EPD_RST: J1.10, TP12.TP, U2.21 (IO23)
FLASH_CS: D9.1, R5.1, U1.1 (!CS), U2.12 (IO11)
GDR: J1.2, Q3.1 (G), R4.2
GND: BOOT_BUTTON.1, BOOT_BUTTON.2, C1.2, C1_BAT.2, C1_BAT1.2, C1_BAT2.2, C2.2, C2_BAT.2, C3.-, C4_USB.2, C5.2, C5_USB.2, C6.2, C7.2, C8.2, C9.2, C10.2, C10_SUPERCAP.1, CHANGE_BUTTON.1, CHANGE_BUTTON.2, C_DELAY.2, D1.2 (GND), D3.1 (K), D6.2, D8.2, D9.2, D10.2, D11.2, D12.2, EPD_C1.1, EPD_C2.1, EPD_C5.1, EPD_C6.1, EPD_C7.1, EPD_C8.1, EPD_C9.1, EPD_C10.1, EPD_C11.1, EPD_C12.1, IC1.3 (GND), IC4.2 (VSS), J1.8, J1.17, J1.MP1, J1.MP2, J2.A1, J2.A12, J2.B1, J2.B12, J2.MP1, J2.MP2, J2.MP3, J2.MP4, J3.1, J4.G1 (GND_1), J4.G2 (GND_2), J4.G3 (GND_3), J4.G4 (GND_4), J4.P6 (VSS), MCP73831.2 (VSS), R1_PWRUSB.1, R2.1, R2-USB.2, R2-USB1.2, R2_BAT.1, R4.1, RESET_BUTTON.1, RESET_BUTTON.2, SENSOR2.1 (GND), SENSOR2.5 (SDO), SENSOR2.7 (GND), SJ1.1, TP4.TP, TP5.TP, U1.4 (GND), U1.9 (EXP), U2.1 (GND), U2.28 (GND), U2.29_1 (GND), U2.29_2 (GND), U2.29_3 (GND), U2.29_4 (GND), U2.29_5 (GND), U2.29_6 (GND), U2.29_7 (GND), U2.29_8 (GND), U2.29_9 (GND), U3.13 (GND), U4.1 (CTG), U4.4 (GND), U4.6 (QSTRT), U4.9 (EP)
GPIO8: R1.1, U2.10 (IO8)
I2C_PW: C1.1, C2.1, R1_PINH.2, R2-PINH.2, SENSOR2.2 (CSB), SENSOR2.6 (VDDIO), SENSOR2.8 (VDD), U2.17 (IO19)
INT_RTC: R1_PINH1.1, TP15.TP, U2.8 (IO0), U3.3 (SQW/!INT)
IO/BOOT: BOOT_BUTTON.3, BOOT_BUTTON.4, C6.1, R_BOOT.1, U2.15 (IO9)
IO/CHANGE: C10.1, CHANGE_BUTTON.3, CHANGE_BUTTON.4, R_CHANGE.1, U2.23 (IO15)
MISO: D12.1, J4.P7 (DAT0), R8.1, TP6.TP, U1.2 (DO(IO1)), U2.27 (IO2)
MOSI: D11.1, J1.14, J4.P3 (CMD), R7.1, TP7.TP, U1.5 (DI(IO0)), U2.7 (IO7)
unnamed: J2.A5, R2-USB1.1
unnamed: J2.B5, R2-USB.1
unnamed: C1_BAT1.1, D2.1 (CATHODE), IC4.1 (VIN), IC4.3 (CE), Q1.2 (S)
unnamed: D7.1 (CATHODE), R_CAPACITOR.1
unnamed: C_DELAY.1, IC1.5 (CT)
unnamed: MCP73831.1 (STAT), R1_BAT.2
unnamed: C4.1, D3.2 (A), D4.1 (K)
unnamed: CHG_LED.C, R1_BAT.1
unnamed: EPD_C12.2, J1.24
unnamed: EPD_C10.2, J1.22
unnamed: EPD_C8.2, J1.20
unnamed: EPD_C7.2, J1.19
unnamed: EPD_C6.2, J1.18
unnamed: MCP73831.5 (PROG), R2_BAT.2
unnamed: EPD_C1.2, J1.4
unnamed: EPD_C2.2, J1.5
PREVGH: D5.1 (K), EPD_C9.2, J1.21
PREVGL: D4.2 (A), EPD_C11.2, J1.23
RESE: J1.3, Q3.2 (S), R3.2
RESE': R2.2, R3.1, SJ1.2
RESET: C5.1, IC1.1 (VOUT), RESET_BUTTON.3, RESET_BUTTON.4, R_RESET.1, U2.3 (EN)
RTC_RST: U2.16 (IO18), U3.4 (!RST)
RX: TP2.TP, U2.24 (RXD0/GPIO17)
SCK: D10.1, J1.13, J4.P5 (CLK), R6.1, TP8.TP, U1.6 (CLK), U2.6 (IO6)
SCL: J3.4, R2-PINH.1, SENSOR2.4 (SCK), U2.20 (IO22), U3.16 (SCL), U4.7 (SCL)
SDA: J3.3, R1_PINH.1, SENSOR2.3 (SDI), U2.19 (IO21), U3.15 (SDA), U4.8 (SDA)
SRC: C4.2, D5.2 (A), L1.1, Q3.3 (D)
SS_SD: D8.1, J4.P2 (CD/DAT3), R10.1, U2.4 (IO4)
TX: TP1.TP, U2.25 (TXD0/GPIO16)
USB_D+: D1.1 (I/O1_1), U2.14 (IO13)
USB_D-: D1.3 (I/O2_1), U2.13 (IO12)
VBAT: C2_BAT.1, MCP73831.3 (VBAT), Q1.3 (D), TP3.TP, U4.2 (CELL), U4.3 (VDD)
VBUS: C1_BAT.1, C4_USB.1, C5_USB.1, CHG_LED.A, D1.5 (VBUS), D2.2 (ANODE), MCP73831.4 (VIN), PFMF.050.1.2, Q1.1 (G), R1_PWRUSB.2, TP14.TP
VRTC: C8.1, C10_SUPERCAP.2, R_CAPACITOR.2, U3.14 (VBAT)
VUSB: J2.A4, J2.A9, J2.B4, J2.B9, PFMF.050.1.1

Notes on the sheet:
USB C connector & ESD protection
LDO Voltage Regulator
SD Card
ESP32 C6
Battery Charge Level
External NOR Flash 64MB
SPI ESD Protection Lines
Qwiic / Stemma QT
Test Pads
RTC Module DS3231SN
E-Paper Display Header
EPD Power
Environmental Sensor BME688
Voltage Supervisor + Reset & Boot / IO Button
Display Type Selector
E-Paper Drive Circuit
Li-Po Battery Charging Controller
OpenBook Schematic
drawn by: Mihai Bianca-Ioana

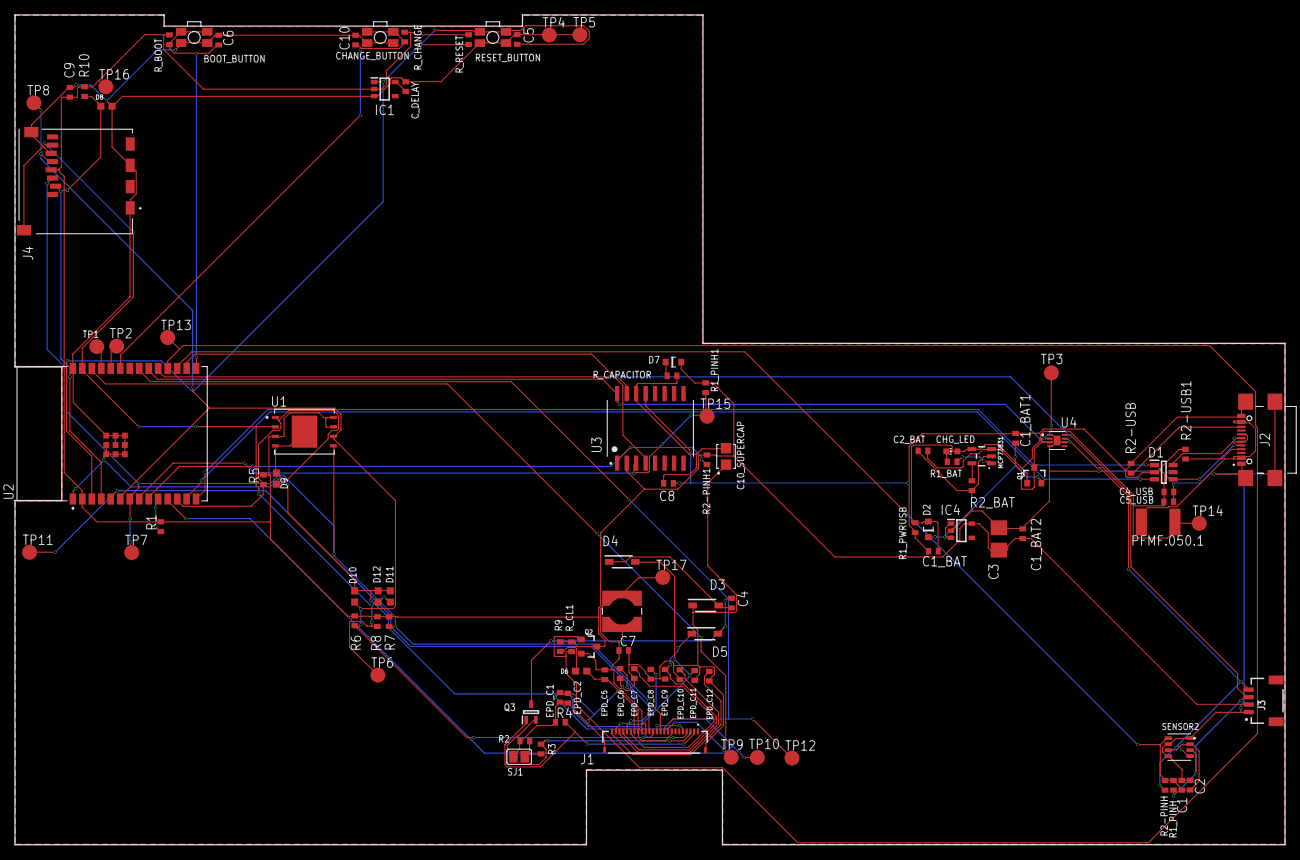
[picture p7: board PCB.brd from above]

Board: 2 copper layers, 170.2 x 111.2 mm, 103 parts (0 on the bottom side), 56 nets.

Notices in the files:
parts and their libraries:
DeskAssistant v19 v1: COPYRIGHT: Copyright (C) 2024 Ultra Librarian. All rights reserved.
